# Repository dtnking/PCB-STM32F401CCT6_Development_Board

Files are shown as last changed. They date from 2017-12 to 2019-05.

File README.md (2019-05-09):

# PCB-STM32F401CCT6_Development_Board
STM32F401CCT6 Development PCB Design using KiCAD

Schemtic:
Schematic

3D Front View:
STM32F103C8_Design_Top

3D Bottow View:
STM32F103C8_Design_Bottom

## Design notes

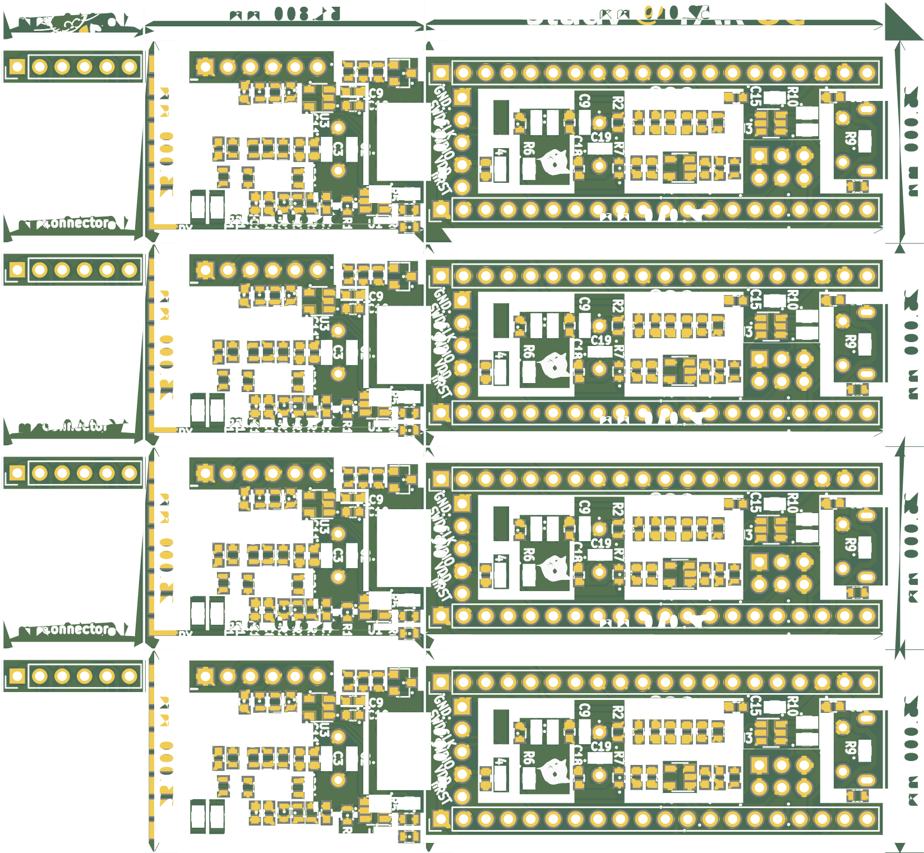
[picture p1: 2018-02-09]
mergeGerber(with proper outline)/Untitled_Combined_Bottom.png

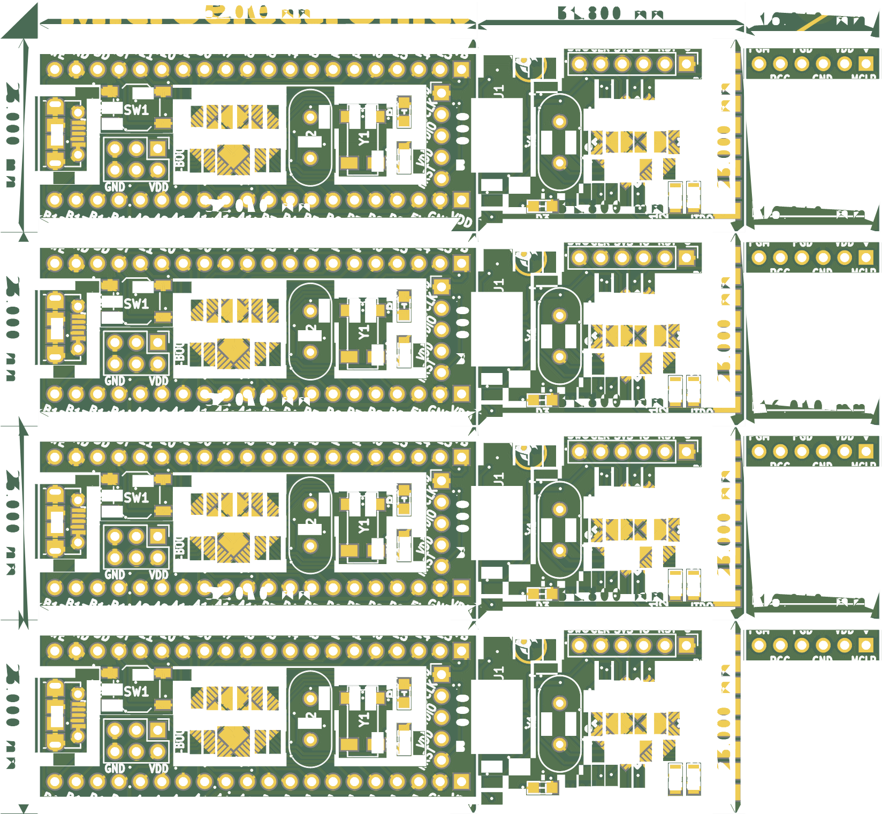
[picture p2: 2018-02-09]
mergeGerber(with proper outline)/Untitled_Combined_Top.png

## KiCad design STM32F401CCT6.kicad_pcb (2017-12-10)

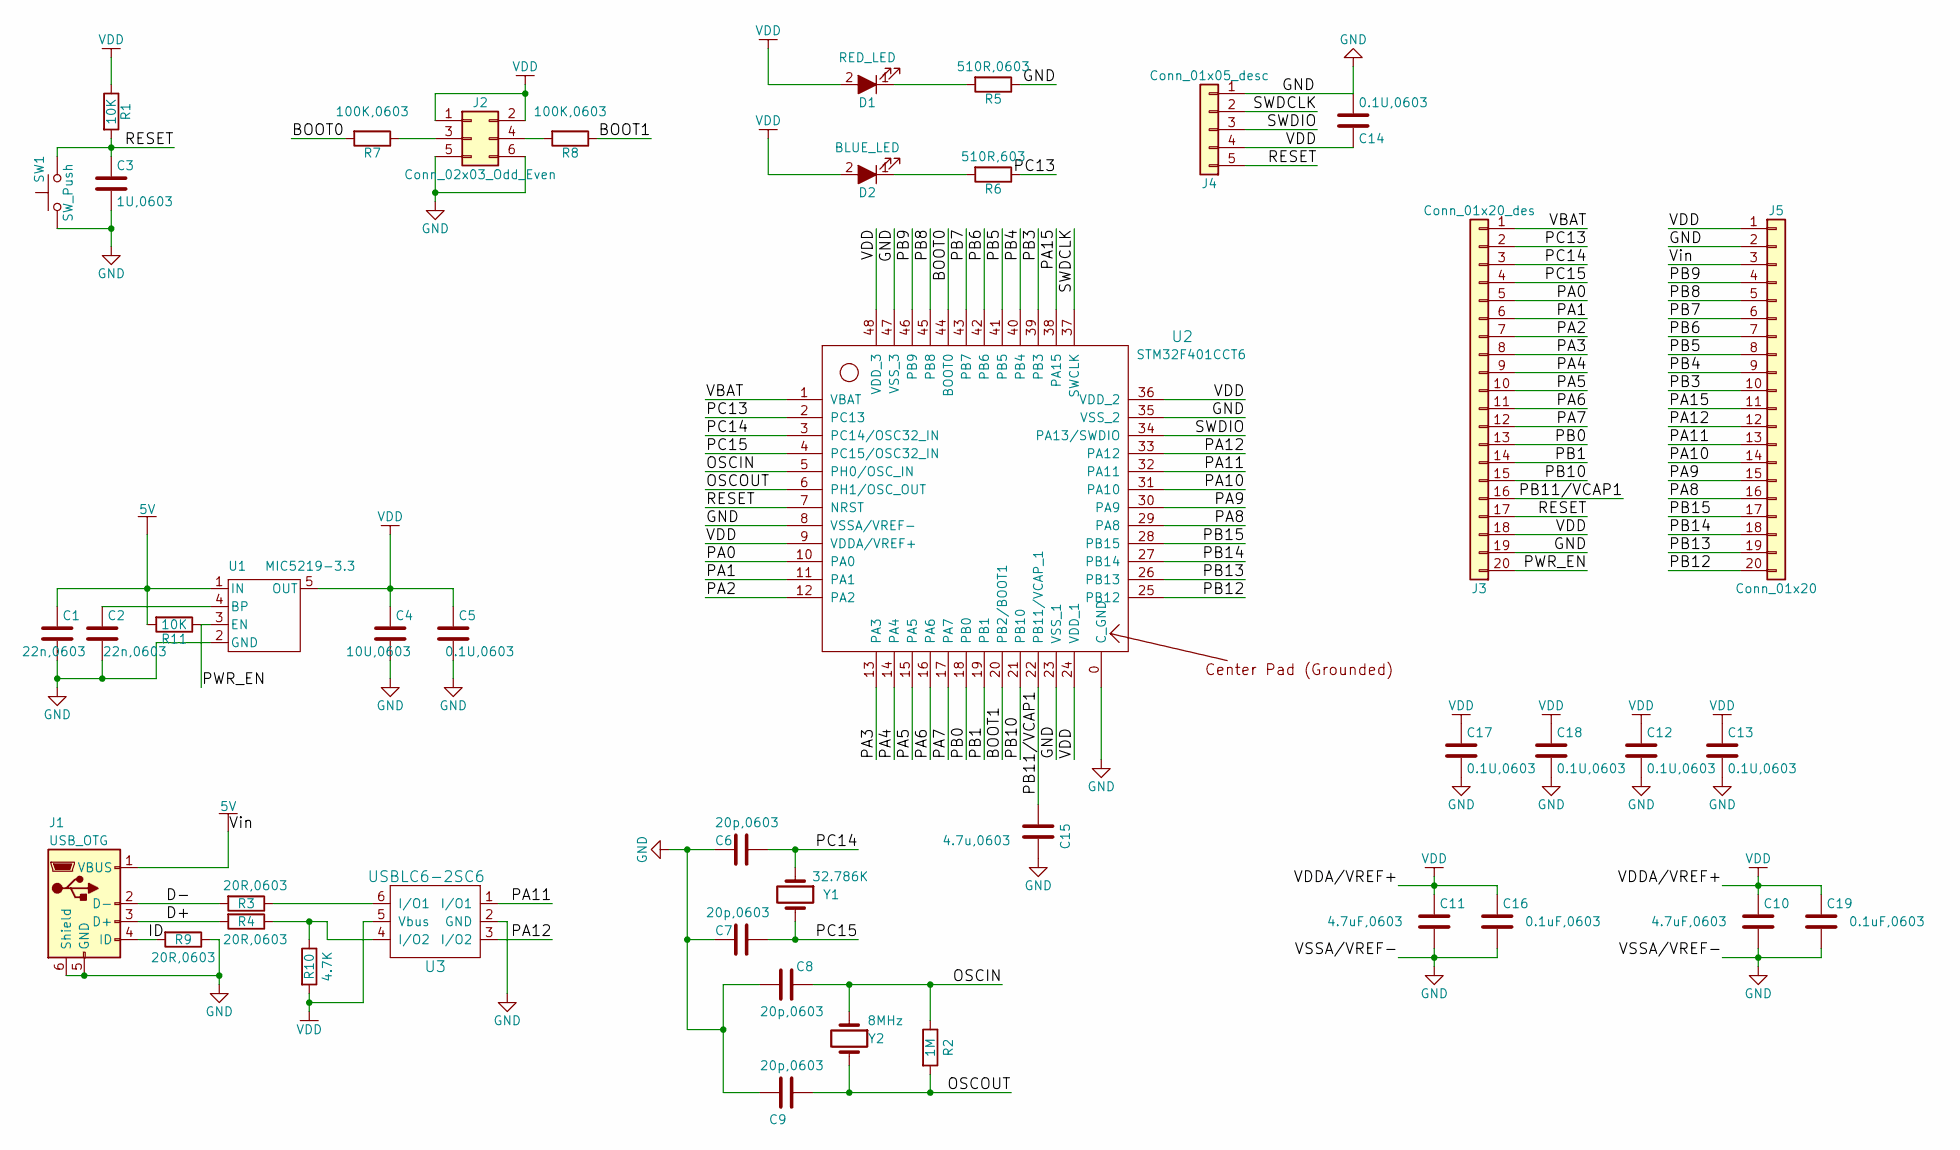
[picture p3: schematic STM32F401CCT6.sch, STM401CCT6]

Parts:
C1, C2: 22n,0603; C_0603
C3: 1U,0603; C_0603
C4: 10U,0603; C_0603
C5, C12, C13, C14, C17, C18: 0.1U,0603; C_0603
C6, C7, C8, C9: 20p,0603; C_0603
C10, C11: 4.7uF,0603; C_0603
C15: 4.7u,0603; C_0603
C16, C19: 0.1uF,0603; C_0603
D1: RED_LED; LED_0805
D2: BLUE_LED; LED_0805
J1: USB_OTG; USB_Micro-B_Molex-105017-0001
J2: Conn_02x03_Odd_Even; Pin_Header_Straight_2x03_Pitch2.54mm
J3: Conn_01x20_des; Pin_Header_Straight_1x20_Pitch2.54mm
J4: Conn_01x05_desc; Pin_Header_Angled_1x05_Pitch2.54mm
J5: Conn_01x20; Pin_Header_Straight_1x20_Pitch2.54mm
R1, R11: 10K; R_0603
R2: 1M; R_0603
R3, R4, R9: 20R,0603; R_0603
R5: 510R,0603; R_0603
R6: 510R,603; R_0603
R7, R8: 100K,0603; R_0603
R10: 4.7K; R_0603
SW1: SW_Push; SW_SPST_TL3342
U1: MIC5219-3.3; SOT-23-5
U2: STM32F401CCT6
U3: USBLC6-2SC6; SOT-23-6
Y1: 32.786K; Crystal_SMD_SeikoEpson_MC306-4pin_8.0x3.2mm
Y2: 8MHz; Crystal_HC49-4H_Vertical

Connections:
+5V: C1.1, J1.1 (VBUS), J5.3, R11.2, U1.1 (IN)
/BOOT0: R7.2, U2.44 (BOOT0)
/BOOT1: R8.1, U2.20 (PB2/BOOT1)
/D+: J1.3 (D+), R4.2
/D-: J1.2 (D-), R3.2
/ID: J1.4 (ID), R9.2
/OSCIN: C8.1, R2.1, U2.5 (PH0/OSC_IN), Y2.1
/OSCOUT: C9.1, R2.2, U2.6 (PH1/OSC_OUT), Y2.2
/PA0: J3.5, U2.10 (PA0)
/PA1: J3.6, U2.11 (PA1)
/PA2: J3.7, U2.12 (PA2)
/PA3: J3.8, U2.13 (PA3)
/PA4: J3.9, U2.14 (PA4)
/PA5: J3.10, U2.15 (PA5)
/PA6: J3.11, U2.16 (PA6)
/PA7: J3.12, U2.17 (PA7)
/PA8: J5.16, U2.29 (PA8)
/PA9: J5.15, U2.30 (PA9)
/PA10: J5.14, U2.31 (PA10)
/PA11: J5.13, U2.32 (PA11), U3.1 (I/O1)
/PA12: J5.12, U2.33 (PA12), U3.3 (I/O2)
/PA15: J5.11, U2.38 (PA15)
/PB0: J3.13, U2.18 (PB0)
/PB1: J3.14, U2.19 (PB1)
/PB3: J5.10, U2.39 (PB3)
/PB4: J5.9, U2.40 (PB4)
/PB5: J5.8, U2.41 (PB5)
/PB6: J5.7, U2.42 (PB6)
/PB7: J5.6, U2.43 (PB7)
/PB8: J5.5, U2.45 (PB8)
/PB9: J5.4, U2.46 (PB9)
/PB10: J3.15, U2.21 (PB10)
/PB11/VCAP1: C15.2, J3.16, U2.22 (PB11/VCAP_1)
/PB12: J5.20, U2.25 (PB12)
/PB13: J5.19, U2.26 (PB13)
/PB14: J5.18, U2.27 (PB14)
/PB15: J5.17, U2.28 (PB15)
/PC13: J3.2, R6.1, U2.2 (PC13)
/PC14: C6.1, J3.3, U2.3 (PC14/OSC32_IN), Y1.1
/PC15: C7.1, J3.4, U2.4 (PC15/OSC32_IN), Y1.2, Y1.4
/PWR_EN: J3.20, R11.1, U1.3 (EN)
/RESET: C3.1, J3.17, J4.5, R1.2, SW1.2, U2.7 (NRST)
/SWDCLK: J4.2, U2.37 (SWCLK)
/SWDIO: J4.3, U2.34 (PA13/SWDIO)
/VBAT: J3.1, U2.1 (VBAT)
/VDD: C4.1, C5.1, C10.1, C11.1, C12.1, C13.1, C14.1, C16.1, C17.1, C18.1, C19.1, D1.2 (A), D2.2 (A), J2.1, J2.2, J3.18, J4.4, J5.1, R1.1, R10.2, U1.5 (OUT), U2.9 (VDDA/VREF+), U2.24 (VDD_1), U2.36 (VDD_2), U2.48 (VDD_3), U3.5 (Vbus)
GND: C1.2, C2.2, C3.2, C4.2, C5.2, C6.2, C7.2, C8.2, C9.2, C10.2, C11.2, C12.2, C13.2, C14.2, C15.1, C16.2, C17.2, C18.2, C19.2, J1.5 (GND), J1.6 (Shield), J2.5, J2.6, J3.19, J4.1, J5.2, R5.1, R9.1, SW1.1, U1.2 (GND), U2.0 (C_GND), U2.8 (VSSA/VREF-), U2.23 (VSS_1), U2.35 (VSS_2), U2.47 (VSS_3), U3.2 (GND)
unnamed: C2.1, U1.4 (BP)
unnamed: D1.1 (K), R5.2
unnamed: D2.1 (K), R6.2
unnamed: J2.3, R7.1
unnamed: J2.4, R8.2
unnamed: R3.1, U3.6 (I/O1)
unnamed: R4.1, R10.1, U3.4 (I/O2)

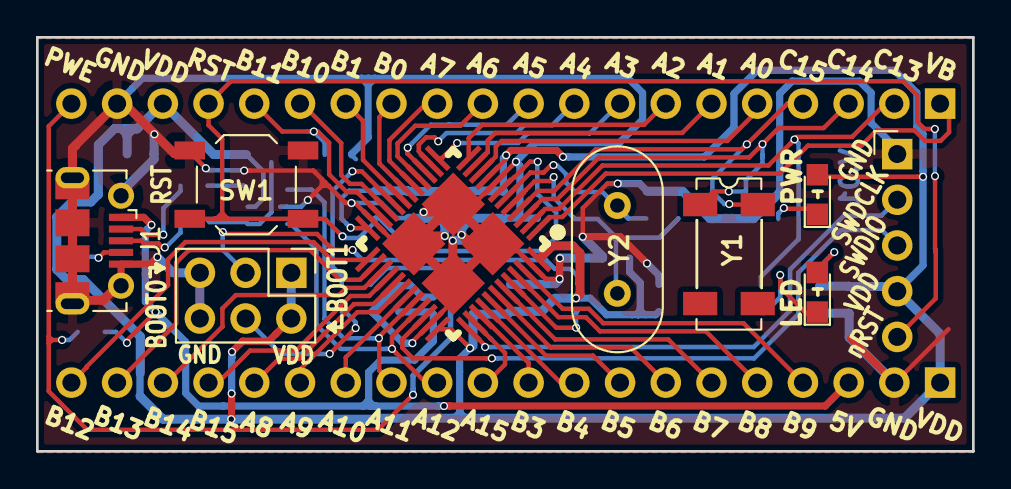
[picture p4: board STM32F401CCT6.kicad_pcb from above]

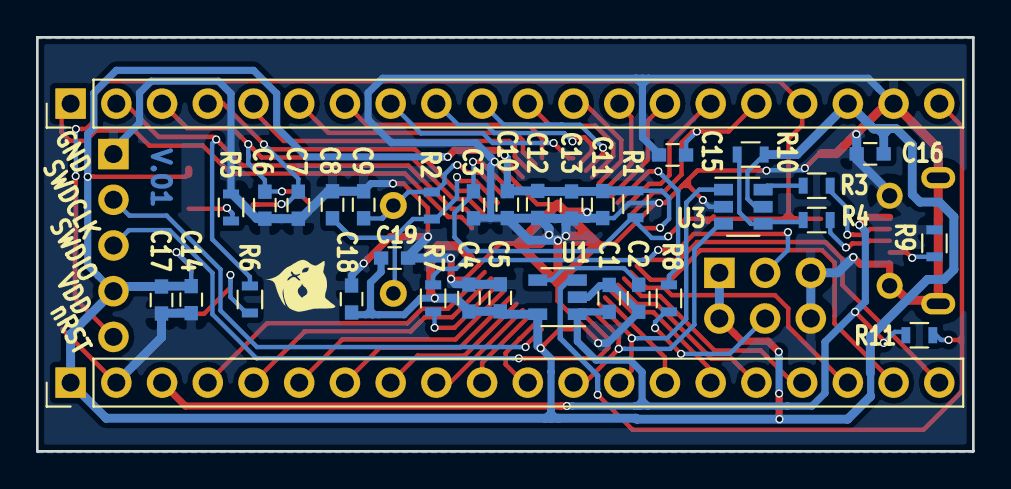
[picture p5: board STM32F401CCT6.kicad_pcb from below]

Board: 2 copper layers, 52.0 x 23.0 mm, 47 parts (35 on the bottom side), 54 nets.

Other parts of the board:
Dot: G***; Dot
HS_Crystal: G***; HS_Crystal
LS_Crystal: G***; LS_Crystal
Meow: G***; Meow

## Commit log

2017-10-03 Drawed the schematic of STM32F401CCT6-without TVS
    [STM32F401CCT6.kicad_pcb, STM32F401CCT6.sch]
2017-10-03 Added USBLC6 component lib
    [STM32F401CCT6.sch]
2017-10-05 Changed pin SWDIO and SWDCLK
    [STM32F401CCT6.sch]
2017-10-06 Assosciated schematic to footprint
    [_saved_STM32F401CCT6.sch]
2017-10-06 Changed LED(schematic)
    [STM32F401CCT6.kicad_pcb, STM32F401CCT6.sch, _saved_STM32F401CCT6.sch]
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2017-10-10 Added copper pour
    [STM32F401CCT6.kicad_pcb, STM32F401CCT6.sch, _saved_STM32F401CCT6.sch]
2017-10-10 Modified QFN-QFP48
    [STM32F401CCT6(NEW).kicad_pcb, _saved_STM32F401CCT6.sch]
2017-10-11 rerouting (left reset)
    [STM32F401CCT6.sch, _saved_STM32F401CCT6.sch]
2017-10-11 Fixed QFPN48 pin 47 and 48 distances to 0.2
    [STM32F401CCT6(NEW).kicad_pcb, _saved_STM32F401CCT6.sch]
2017-10-11 Finish routing
    [STM32F401CCT6(NEW).kicad_pcb, STM32F401CCT6.sch, _saved_STM32F401CCT6.sch]
2017-10-12 Added pin name on silk layer
    [STM32F401CCT6(NEW).kicad_pcb]
2017-10-12 Finish design the layout-Added Image on it
    [STM32F401CCT6(NEW).kicad_pcb]
2017-10-13 Changed footprint from handsoldering to none
    [STM32F401CCT6(NEW).kicad_pcb, _saved_STM32F401CCT6.sch]
2017-10-13 Moved the pin connector to bottom layer
    [STM32F401CCT6.sch, _saved_STM32F401CCT6.sch]
2017-10-13 Rotated the neko image
    [STM32F401CCT6(NEW).kicad_pcb]
2017-10-17 Changed via size to 0.45/0.3mm and generated Gerber file
    [STM32F401CCT6-B.CrtYd.gbr, STM32F401CCT6-B.Cu.gbl, STM32F401CCT6-B.Mask.gbs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]
2017-10-20 Modified routing
    [STM32F401CCT6.kicad_pcb]
2017-10-22 Moved the pin indicator(silk layer) further away from the edge cut
    [STM32F401CCT6.kicad_pcb]
2017-10-23 Moved Micro_USB further out and reroute some tracks
    [STM32F401CCT6.kicad_pcb]
2017-10-24 Moved the bottom edge cut further inwards
    [STM32F401CCT6.kicad_pcb, STM32F401CCT6.sch]
2017-10-30 Widen the track of power source
    [STM32F401CCT6(NEW).kicad_pcb]
2017-10-30 Added corner outline as an indicator for the footprint QFP48
    [STM32F401CCT6(NEW).kicad_pcb]
2017-10-31 Adjusted the size of the label indicator
    [STM32F401CCT6(NEW).kicad_pcb, STM32F401CCT6.kicad_pcb]
2017-11-05 Updated the via diamter and drill size 0.435/0.3 mm
    [STM32F401CCT6(NEW).kicad_pcb, STM32F401CCT6.sch]
2017-11-06 Added extra capacitor between VDD and GND (VFFA-VSSA)
    [STM32F401CCT6-B.CrtYd.gbr, STM32F401CCT6-B.Cu.gbl, STM32F401CCT6-B.Mask.gbs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]
2017-11-06 Fixed the pad near tracks error (reallocated the QFN)
    [STM32F401CCT6.kicad_pcb, STM32F401CCT6.sch]
2017-11-07 Change pin20 to Pwr Enable and added a resistor on it
    [STM32F401CCT6-B.CrtYd.gbr, STM32F401CCT6-B.Cu.gbl, STM32F401CCT6-B.Mask.gbs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]
2017-11-07 Changed pin 20 to PWE schemaic
    [STM32F401CCT6.sch, _saved_STM32F401CCT6.sch]
2017-11-09 Re-routed (prioritised D+ D- SWDIO SWCLK) by reducing the track length and via along the tracks.
    [STM32F401CCT6(NEW).kicad_pcb, STM32F401CCT6.kicad_pcb, STM32F401CCT6.sch]
2017-11-09 Changed the via size to 0.453/0.3 mm
    [STM32F401CCT6.kicad_pcb]
2017-11-12 Renamed VCC to VDD
    [STM32F401CCT6.kicad_pcb, STM32F401CCT6.sch]
2017-11-13 Added indication for LED footprint and added dimension on Eco1.user layer
    [STM32F401CCT6.kicad_pcb, STM32F401CCT6.sch]
2017-11-14 Change the route nicely
    [STM32F401CCT6-B.CrtYd.gbr, STM32F401CCT6-B.Cu.gbl, STM32F401CCT6-B.Mask.gbs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]
2017-11-15 Panelized with other PCB
    [STM32F401CCT6(NEW).kicad_pcb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]
2017-11-16 Removed the silk layer of angled pin header and move the bottom pin label downward
    [STM32F401CCT6-B.CrtYd.gbr, STM32F401CCT6-B.Cu.gbl, STM32F401CCT6-B.Mask.gbs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]
2017-11-16 Produced merged gerber file of STM32 board together with RJ12 and ST-Link
    [combined.GKO, combined.drl, combined.gbl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]
2017-11-16 Changed the 4 corner labels indication for footprint of QFN-QFP
    [STM32F401CCT6-B.CrtYd.gbr, STM32F401CCT6-B.Cu.gbl, STM32F401CCT6-B.Mask.gbs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]
2017-11-17 Found missing bottom silk layer, placed it back
    [STM32F401CCT6-B.CrtYd.gbr, STM32F401CCT6-B.Cu.gbl, STM32F401CCT6-B.Mask.gbs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]
2017-11-17 Enlarged the QFN-QFP48 footprint pin 1 indication label and the dimension label from 0.3mm to 0.4mm
    [STM32F401CCT6-B.CrtYd.gbr, STM32F401CCT6-B.Cu.gbl, STM32F401CCT6-B.Mask.gbs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]
2017-11-17 Regenerated combined gerber file (with ST-Link and RJ12)
    [combined.drl, combined.gbl, combined.gbo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]
2017-11-17 Removed older PCB file
2017-11-17 Renamed the merge gerber folder
    [combined.GKO, combined.drl, combined.gbl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]
2017-11-17 Renamed the pin3 track label from ST-Link to Vin
    [STM32F401CCT6.sch]
2017-11-18 Moved silk layer away from via and swap the position of VDD with nRST pin of the SWDIO
    [STM32F401CCT6-B.CrtYd.gbr, STM32F401CCT6-B.Cu.gbl, STM32F401CCT6-B.Mask.gbs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]
2017-11-20 Added a new footprint for Micro USB (non-Complete)
    [STM32F401CCT6-B.CrtYd.gbr, STM32F401CCT6-B.Cu.gbl, STM32F401CCT6-B.Mask.gbs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]
2017-11-22 Replace the Micro-USB footprint with the one newly created, added a shield for MCU (grounded pin), moved some component inwards to prevent touching the pinheader plastic.
    [STM32F401CCT6.kicad_pcb, STM32F401CCT6.sch]
2017-11-22 Re-generated gerber files for panelizing
    [STM32F401CCT6-B.CrtYd.gbr, STM32F401CCT6-B.Cu.gbl, STM32F401CCT6-B.Mask.gbs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]
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2017-11-29 Moved the indicator of LED slightly to the right
    [STM32F401CCT6-B.CrtYd.gbr, STM32F401CCT6-B.Cu.gbl, STM32F401CCT6-B.Mask.gbs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]
2017-12-01 Replaced the MCU footprint
    [STM32F401CCT6-B.CrtYd.gbr, STM32F401CCT6-B.Cu.gbl, STM32F401CCT6-B.Mask.gbs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]
2017-12-03 Changed the kitty silk layer
    [STM32F401CCT6-B.CrtYd.gbr, STM32F401CCT6-B.Cu.gbl, STM32F401CCT6-B.Mask.gbs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]
2017-12-05 changed the copper pour clearance
    [STM32F401CCT6.kicad_pcb]
2017-12-10 Change back the Micro_usb footprint to THT footprint
    [STM32F401CCT6-B.CrtYd.gbr, STM32F401CCT6-B.Cu.gbl, STM32F401CCT6-B.Mask.gbs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]
2018-01-16 Generated gerber file with drill hole of trailing zero format
    [STM32F401CCT6-B.CrtYd.gbr, STM32F401CCT6-B.Cu.gbl, STM32F401CCT6-B.Mask.gbs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]
2018-02-09 Resolved the problem of silk layer does not shown up
    [combined.GKO, combined.drl, combined.gbl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]
